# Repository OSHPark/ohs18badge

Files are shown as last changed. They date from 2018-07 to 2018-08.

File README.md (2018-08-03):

## Open Hardware Summit 2018 badge
* Additonal details to be announced
* Visit the [Hackaday.io project](https://hackaday.io/project/112222-2018-open-hardware-summit-badge) for discussion
* Future documenation website: https://oshwabadge2018.github.io

### Description
OSH Park will be producing electronic conference badges for the [2018 Open Hardware Summit](http://2018.oshwa.org/) on September 27th at MIT

The current concept is to have:
* ESP32 microcontroller with WiFi and Bluetooth
* E-Paper to display the badge wearer's name
* Use wireless communication (WiFi or BLE) to allow badge wearer to update the displayed text from an Android or iOS phone

Quantity 300 badges are required for OHS 2018 on September 27th.

Maximum total budget per badge is: $25
(that will have to include components, batteries, PCB, assembly, lanyard, packaging)

Production plan:
The badge circuit boards will be pick-n-place assembled by a professional assembly service. A test jig will need to be created for the assembler to test the badges.

Production deadline:
September 1st, 2018

## OSHWA Certified Open Source Hardware
* Open Hardware Summit 2018 badge has now officially been certified as open source hardware by the Open Source Hardware Association. 
* UID is: US000133
* Details: http://certificate.oshwa.org/certification-directory/

## License
CERN Open Hardware Licence v1.2

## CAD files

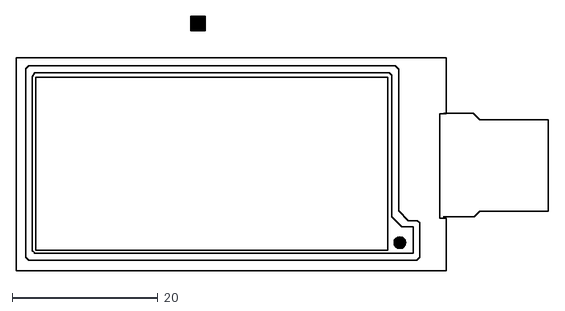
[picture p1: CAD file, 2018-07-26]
Art/213eink-4.dxf
73.1 x 35.0

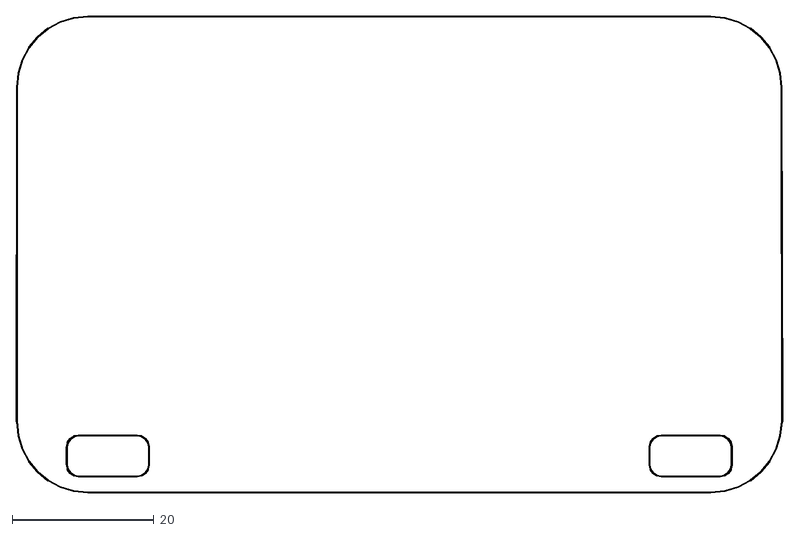
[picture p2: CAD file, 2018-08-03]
exported-artwork/oshw2018badgeprototype-Edge.Cuts.dxf
108.1 x 67.3

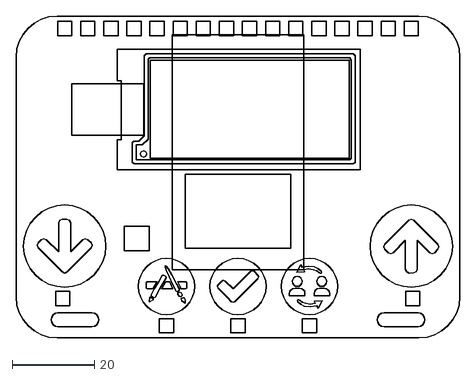
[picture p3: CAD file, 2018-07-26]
Art/BADGE-PRELIM-SINGLESIDE.dxf
107.9 x 78.2

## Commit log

2018-06-06 Commit of local files.
    Kicad project with libraries and schematic added.
    [213eink-4.dxf, _saved_oshw2018badgeprototype.sch, oshw2018badgeprototype.kicad_pcb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]
2018-06-09 Made some progress on the PCB.
    Made some progress on the PCB.
    Added a bunch of footrpints and Libraries
    [BADGE-PRELIM-SINGLESIDE.dxf, oshw2018badgeprototype.kicad_pcb, oshw2018badgeprototype.sch]
2018-06-09 Removed old board outlines
    Removed old board outlines
    [oshw2018badgeprototype.kicad_pcb]
2018-06-10 Routing Complete
    Routing Complete
    [_saved_oshw2018badgeprototype.sch, oshw2018badgeprototype.kicad_pcb, oshw2018badgeprototype.sch]
2018-06-10 routed INT wire
    didnt route int wire
    [oshw2018badgeprototype.kicad_pcb]
2018-06-10 Fixed DRC errors
    Fixed DRC errors
    [_saved_oshw2018badgeprototype.sch, oshw2018badgeprototype.kicad_pcb]
2018-06-10 Cleaned up routing
    [oshw2018badgeprototype.kicad_pcb]
2018-06-10 Shitty Connector and Power Button Circut Change
    Changed the circut for the power button and battery sense.
    added the shitty badge connector.
    [_saved_oshw2018badgeprototype.sch, oshw2018badgeprototype.kicad_pcb, oshw2018badgeprototype.sch]
2018-06-10 More Via Stitching
    [oshw2018badgeprototype.kicad_pcb]
2018-06-10 Added icon next to power button
    [oshw2018badgeprototype.kicad_pcb]
2018-06-10 Silk Screen Edits
    Added OSHW logo
    Added Labels
    [oshw2018badgeprototype.kicad_pcb]
2018-06-10 Generated Bom and Cleaned up Sinkscreen
    [_saved_oshw2018badgeprototype.sch, oshw2018badgeprototype.kicad_pcb, oshw2018badgeprototype_bom_.csv]
2018-06-11 reduced board sq in
    [oshw2018badgeprototype.kicad_pcb]
2018-06-11 Reduced board outline.
    Reduced board outline.
    [oshw2018badgeprototype.kicad_pcb]
2018-06-11 fixed stub
    fixed stub
    [oshw2018badgeprototype.kicad_pcb]
2018-06-11 fixed trace that intersected copper pour
    [oshw2018badgeprototype.kicad_pcb]
2018-06-12 Routing done on shruken badge
    [_saved_oshw2018badgeprototype.sch, oshw2018badgeprototype.kicad_pcb, oshw2018badgeprototype.sch]
2018-06-13 Cleaned up top silk
    [oshw2018badgeprototype.kicad_pcb]
2018-07-02 Fixed pinout of power SW
    Fixed pinout of power SW
    [oshw2018badgeprototype.kicad_pcb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]
2018-07-02 Changed R8 to 100k
    [oshw2018badgeprototype.sch]
2018-07-02 Fixed battery connector footprint.
    [oshw2018badgeprototype.kicad_pcb]
2018-07-04 Fixed accelerometer.
    Fixed accelerometer.
    [oshw2018badgeprototype.kicad_pcb, oshw2018badgeprototype.sch]
2018-07-04 Added pulldown to GDR
    [oshw2018badgeprototype.kicad_pcb, oshw2018badgeprototype.sch]
2018-07-04 Forgot to connect R10 to 3.3v
    [oshw2018badgeprototype.kicad_pcb]
2018-07-04 fixed LEDs
    Fixed LED footprint, fixed traces, reduced LEDs to 6
    [_saved_oshw2018badgeprototype.sch, oshw2018badgeprototype.kicad_pcb, oshw2018badgeprototype.sch]
2018-07-05 Fix current sensor value
    Current sense resistor is 2.2 ohms
    [_saved_oshw2018badgeprototype.sch, oshw2018badgeprototype.sch]
2018-07-05 Fixed CD line and L1
    [oshw2018badgeprototype.kicad_pcb]
2018-07-05 Added cap tp pin4 of epd
    [oshw2018badgeprototype.kicad_pcb, oshw2018badgeprototype.sch]
2018-07-07 MAny Changes
    Changed SD card to use spi.
    Changed EInk CD line to alternate gpio pin.
    Fixed problem with LEDs
    Updated Eink pads and traces.
    [oshw2018badgeprototype.kicad_pcb, oshw2018badgeprototype.sch]
2018-07-07 Updating Via stitches
    [oshw2018badgeprototype.kicad_pcb]
2018-07-07 net names on cap touch pads fixed
    [oshw2018badgeprototype.kicad_pcb]
2018-07-07 Fixed solder mask clearence
    [oshw2018badgeprototype.kicad_pcb]
2018-07-08 Added programming transistors
    [oshw2018badgeprototype.kicad_pcb, oshw2018badgeprototype.sch]
2018-07-09 Post Design Review Changes.
    Fixed silk
    Fixed ugly traces
    added hatched ground pour
    Fixed problems with LED footprint.
    Fixed incorrect SD card wiring.
    [oshw2018badgeprototype.kicad_pcb, oshw2018badgeprototype.sch]
2018-07-09 pushing pcb
2018-07-09 fixed accidently rotated battery footprint
    [oshw2018badgeprototype.kicad_pcb]
2018-07-09 fixed disconnected traces.
    [oshw2018badgeprototype.kicad_pcb]
2018-07-09 Dropped pour clearence to 0.25
    [oshw2018badgeprototype.kicad_pcb]
2018-07-09 Fixed more silk errors
    [oshw2018badgeprototype.kicad_pcb]
2018-07-11 added OHS logo
    [oshw2018badgeprototype.kicad_pcb]
2018-07-31 Updated to kicad 5
    [_saved_oshw2018badgeprototype.sch, oshw2018badgeprototype_bom_.csv]
2018-07-31 Upodated to kicad 5
2018-07-31 Rev3 Schematic Changes
    Cleaned up schematic
    * Removed LEDs
    * Removed auto-programming circut (not needed)
    * Cleaned up Schematic
    [_saved_oshw2018badgeprototype.sch, oshw2018badgeprototype.sch]
2018-07-31 Updated PCBs
    Updated PCBs to reflect schematic changes.
    Grounded the 6th connector on the programming header (previously NC)
    [oshw2018badgeprototype-Edge.Cuts.dxf, oshw2018badgeprototype.kicad_pcb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]
2018-08-03 Improved silkscreen Artwork and added Testpoints
    [_saved_oshw2018badgeprototype.sch, oshw2018badgeprototype.kicad_pcb]
2018-08-03 Added Footprint for OSHWA Cert logo
2018-08-04 Added Screaming and OSH logos to PCB
    [oshw2018badgeprototype.kicad_pcb]
2018-08-04 ignore pcbback files
2018-08-15 Final Tweaks for production release
    Fixed Circuits mispelling in silkscreen.
    added missing testpoint labels
    scootched shitty badge addon connector down a few thou.
    [oshw2018badgeprototype.kicad_pcb]
2018-08-15 Changed revision in silk to 4
    [oshw2018badgeprototype.kicad_pcb]
